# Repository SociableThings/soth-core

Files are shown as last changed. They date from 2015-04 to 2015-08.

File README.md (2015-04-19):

# soth-core

---

## About
Hardware core module for Sociable Things Agent.

## Architecture

Agent



Core

Architecture

## Data format
### GPS
```
{
    "year": 2015,
    "month": 4,
    "day": 12,
    "hour": 14,
    "minute": 0,
    "second": 48,
    "validity": 1,
    "latitude": 35.69020,
    "longitude": 139.69001,
    "speed": 0.74,
    "heading": 102.72
}
```

## Progress

Now prototyping





## GPS bore data

valid GPRMC

```
$GPGGA,150754.000,3540.6036,N,13940.9576,E,2,5,1.85,67.2,M,39.4,M,0000,0000*6A
$GPGLL,3540.6036,N,13940.9576,E,150754.000,A,D*5D
$GPGSA,A,3,28,03,01,06,17,,,,,,,,2.08,1.85,0.95*00
$GPGSV,4,1,13,03,71,081,15,28,56,235,35,17,49,320,16,01,42,051,15*77
$GPGSV,4,2,13,11,32,077,,32,27,046,,06,20,269,35,04,17,067,*76
$GPGSV,4,3,13,23,17,136,,09,05,164,,10,05,213,,44,04,260,*74
$GPGSV,4,4,13,19,03,118,*48
$GPRMC,150754.000,A,3540.6036,N,13940.9576,E,0.06,198.48,110415,,,D*60
$GPVTG,198.48,T,,M,0.06,N,0.12,K,D*31
```

invalid GPRMC

```
$GPRMC,142307.497,V,,,,,0.00,0.00,110415,,,N*44
```

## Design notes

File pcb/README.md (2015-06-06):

# soth-core PCB

---

## BOM list

| Parts # | Parts Name | Manufacture Parts # | Footprint | Pin | Manufacture | Source | Document |
|---:|---:|---:|---:|----:|---:|---:|---:|
| U1| MCU| ATXMEGA32D4-AUR| TQFP| 44| Atmel |[Akizuki](http://akizukidenshi.com/catalog/g/gI-06993/)|[AVR XMEGA D Manual](http://www.atmel.com/ja/jp/Images/Atmel-8210-8-and-16-bit-AVR-Microcontrollers-XMEGA-D_Manual.pdf), [ATxmega32D4 Complete](http://www.atmel.com/ja/jp/Images/Atmel-8135-8-and-16-bit-AVR-microcontroller-ATxmega16D4-32D4-64D4-128D4_datasheet.pdf)|
| IC1|USB Serial Conv.| AE-FT231X(FT231X)|DIP(500MIL)| 18| Akizuki|[Akizuki](http://akizukidenshi.com/catalog/g/gK-06894/)|[Manual](http://akizukidenshi.com/download/ds/akizuki/ae_ft231x_manual.pdf)|
| IC3,4|  3-State Buffer| TC7SZ125F| SSOP| 5| Toshiba|[Akizuki](http://akizukidenshi.com/catalog/g/gI-06481/)|[Datasheet](http://toshiba.semicon-storage.com/info/docget.jsp?did=20048&prodName=TC7SZ125FU)|
| IC5| Pressure Sensor| 12113(LPS331AP)| DIP| 10|Strawberry Linux|[Strawberry Linux](https://strawberry-linux.com/catalog/items?code=12113)|[Manual](https://strawberry-linux.com/pub/lps331ap-manual.pdf)|

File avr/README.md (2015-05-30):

# soth-core-avr

---

## Specification

### MCU
- Type name: ATXMEGA32D4-AU
- Foot print: TQFP44
- Spec
  - 32kB Flash
  - 2kB EEPROM
  - 4kB SRAM
- Voltage: 3.3V
- Xtal: 1MHz

### GPS
- Type name: LS20031(LS23060)
- Voltage: 3.3V
- Update rate: 1 sample/s (default: 5 sample/s)
- Baud rate: 9600bps (default: 57600bps)
- Software UART
  - Rx: PC6
  - Tx: PC7

### Communication
- Baud rate: 115200bps
- Hardware UART
  - USARTC

### Command servo
- Type name: RS304MD
- Motor voltage: 5.0V
- Signal voltage: 3.3V
- Baud rate: 115200bps
- Hardware UART
  - USARTD
- Servo ID
  - 1: Front right
  - 2: Front left
  - 3: Back right
  - 4: Back left
  - 5: Yaw
- Reverse the direction?
  - 1: Yes
  - 2: No
  - 3: No
  - 4: Yes
  - 5: No
- Angle limit: CCW:-16.0 deg, CW: 110.0 deg

## Functions
### CMD Servo
#### Change Servo ID
Change servo ID from 1 to 5

```
changeIdCmdServo(1, 5);
```

#### Revserse direction
```
reverseDirection(1, CMD_SERVO_REVERSE); // reverse
```

#### Change angle limit
```
setAngleLimit(1, CMD_SERVO_ANGLE_LIMIT_MAX, CMD_SERVO_ANGLE_LIMIT_MIN);
```

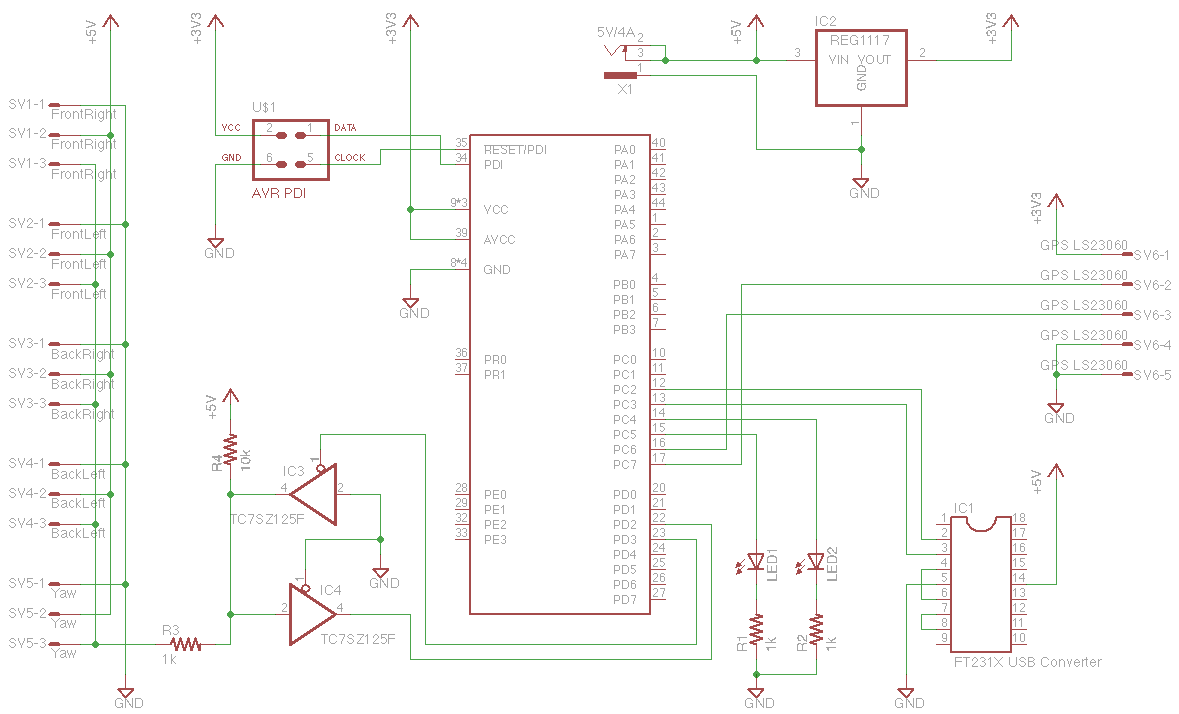
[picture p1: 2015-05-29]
pcb/prototype/schematic.png

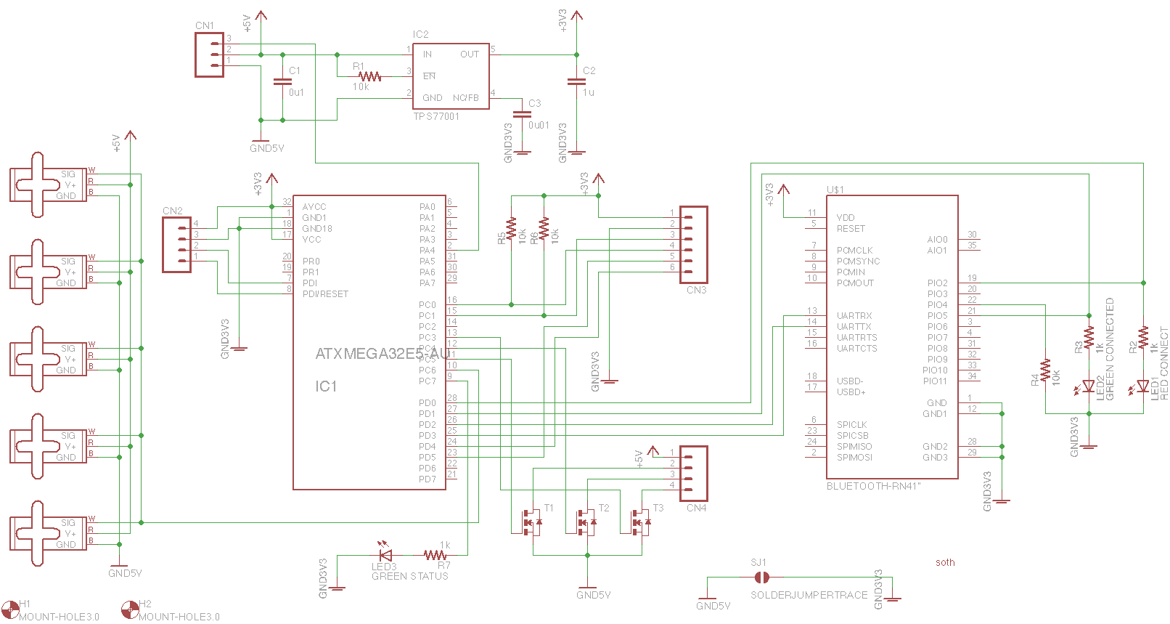
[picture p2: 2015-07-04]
pcb/v0.1/core/soth-core.png

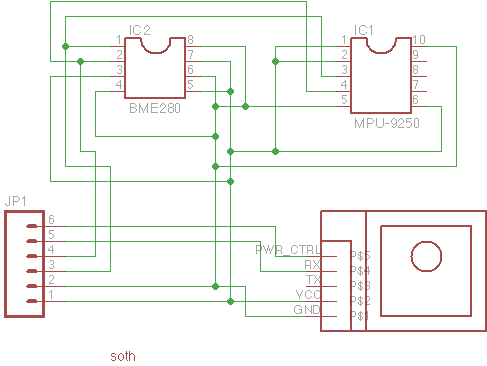
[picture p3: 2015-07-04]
pcb/v0.1/extension/soth-ext.png

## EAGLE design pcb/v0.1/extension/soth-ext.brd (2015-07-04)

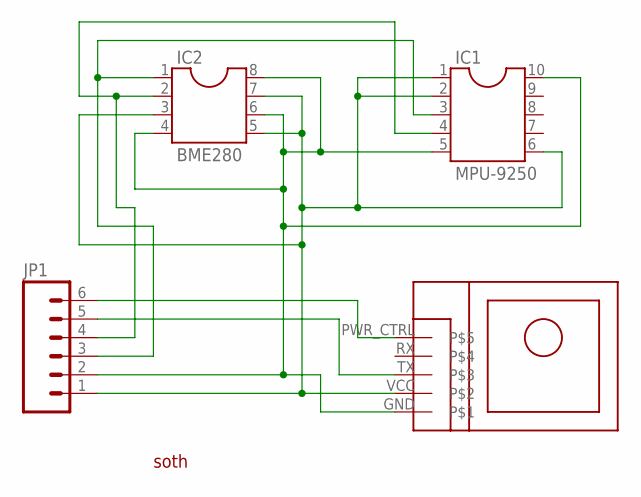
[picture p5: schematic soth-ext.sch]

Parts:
IC1: MPU-9250; DIL10
IC2: BME280; DIL08
JP1: M06SILK_FEMALE_PTH; 1X06
U$1: GM318B
U$2: SOTH_LOGO; SILK_LOGO

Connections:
GND: IC1.5, IC1.10, IC2.4, IC2.6, IC2.8, JP1.2, U$1.GND
unnamed: IC1.1, IC1.2, IC1.6, IC2.3, IC2.5, IC2.7, JP1.1, U$1.VCC
unnamed: JP1.5, U$1.TX
unnamed: JP1.6, U$1.PWR_CTRL
unnamed: IC1.4, IC2.2, JP1.4
unnamed: IC1.3, IC2.1, JP1.3

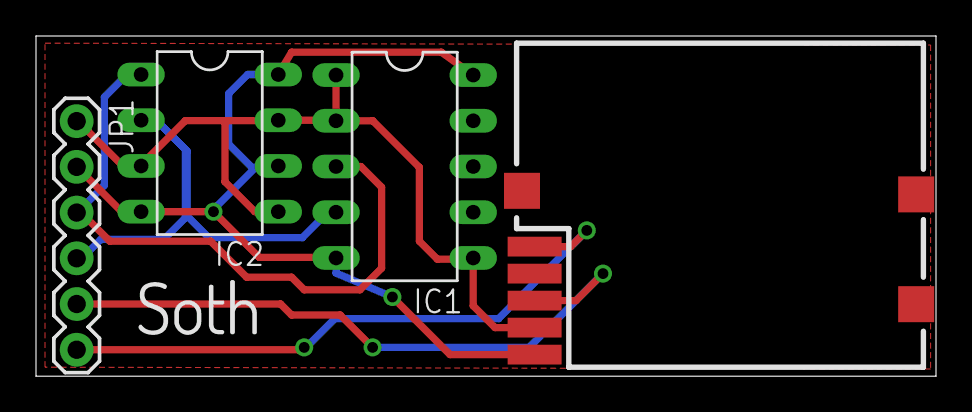
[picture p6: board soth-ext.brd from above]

Board: 2 copper layers, 50.0 x 18.9 mm, 5 parts (0 on the bottom side), 6 nets.

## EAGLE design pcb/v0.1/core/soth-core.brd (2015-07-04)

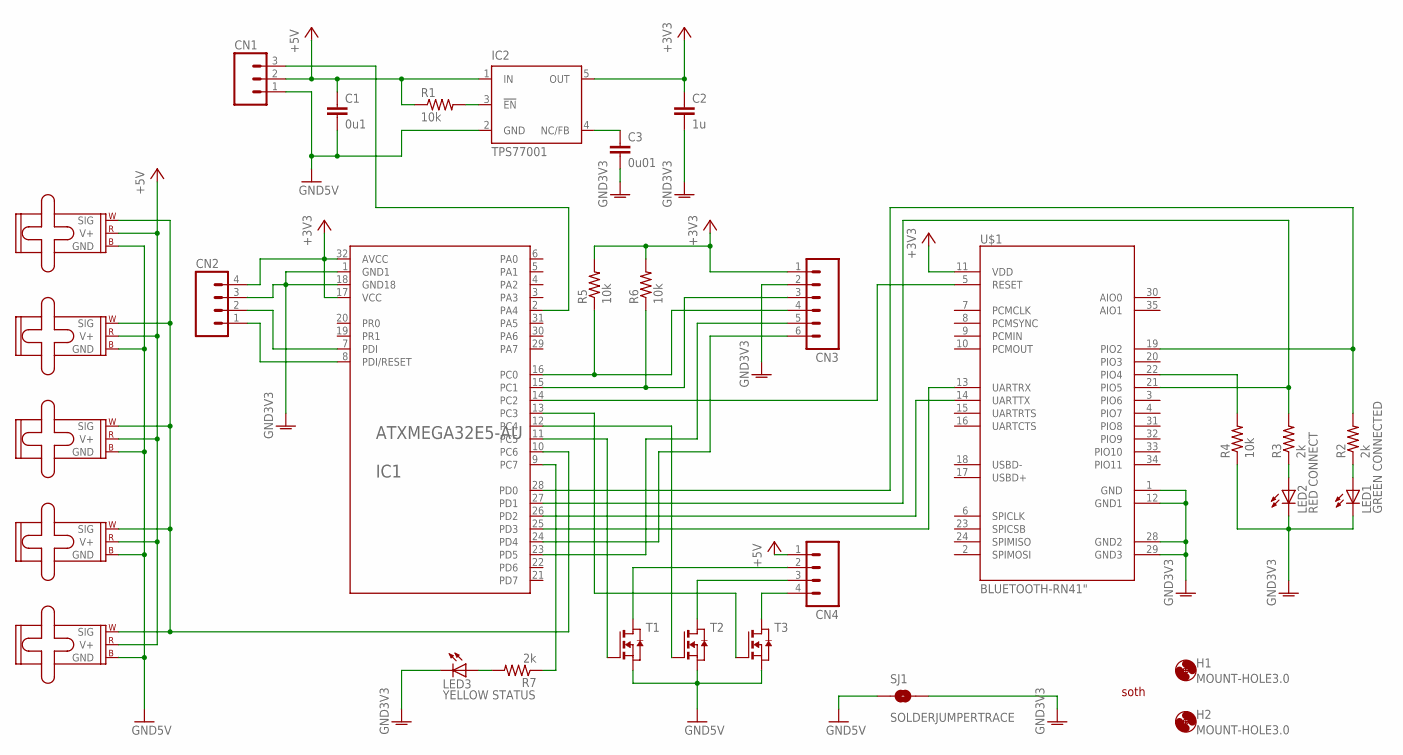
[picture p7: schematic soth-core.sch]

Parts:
C1: 0u1; C1608
C2: 1u; C1608
C3: 0u01; C1608
CN1: M03PTH; 1X03
CN2, CN4: M04PTH; 1X04
CN3: M06SILK_FEMALE_PTH; 1X06
H1, H2: MOUNT-HOLE3.0; 3,0
IC1: ATXMEGA32E5-AU; TQFP32-08
IC2: TPS77001; SOT23-DBV
LED1: GREEN CONNECTED; CHIPLED_1206
LED2: RED CONNECT; CHIPLED_1206
LED3: YELLOW STATUS; CHIPLED_1206
M1, M2, M3, M4, M5: SMALL_SERVO; 1X03
R1, R4, R5, R6: 10k; R0603
R2, R3, R7: 2k; R0603
SJ1: SOLDERJUMPERTRACE; SJ_2S-TRACE
T1, T2, T3: NMOSSOT23; SOT-23
U$1: BLUETOOTH-RN41"; RN41
U$2: SOTH_LOGO; SILK_LOGO

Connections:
+3V3: C2.1, CN2.4, CN3.1, IC1.17 (VCC), IC1.32 (AVCC), IC2.5 (OUT), R5.2, R6.2, U$1.11 (VDD)
+5V: C1.1, CN1.2, CN4.1, IC2.1 (IN), M1.2 (V+), M2.2 (V+), M3.2 (V+), M4.2 (V+), M5.2 (V+), R1.1
GND: C1.2, CN1.1, IC2.2 (GND), M1.3 (GND), M2.3 (GND), M3.3 (GND), M4.3 (GND), M5.3 (GND), SJ1.1, T1.2 (S), T2.2 (S), T3.2 (S)
GNDA: C2.2, C3.2, CN2.3, CN3.2, IC1.1 (GND1), IC1.18 (GND18), LED1.C, LED2.C, LED3.C, R4.1, SJ1.2, U$1.1 (GND), U$1.12 (GND1), U$1.28 (GND2), U$1.29 (GND3)
unnamed: CN4.2, T1.1 (D)
unnamed: IC2.3 (!EN), R1.2
unnamed: IC1.26 (PD2), U$1.14 (UARTTX)
unnamed: CN2.2, IC1.7 (PDI)
unnamed: CN2.1, IC1.8 (PDI/RESET)
unnamed: IC1.25 (PD3), U$1.13 (UARTRX)
unnamed: IC1.27 (PD1), R3.2, U$1.21 (PIO5)
unnamed: LED2.A, R3.1
unnamed: LED1.A, R2.1
unnamed: IC1.28 (PD0), R2.2, U$1.19 (PIO2)
unnamed: R4.2, U$1.22 (PIO4)
unnamed: CN3.4, IC1.16 (PC0), R5.1
unnamed: CN3.3, IC1.15 (PC1), R6.1
unnamed: CN1.3, IC1.2 (PA4)
unnamed: CN4.3, T2.1 (D)
unnamed: CN4.4, T3.1 (D)
unnamed: IC1.9 (PC7), R7.1
unnamed: IC1.11 (PC5), T1.3 (G)
unnamed: CN3.6, IC1.24 (PD4)
unnamed: IC1.10 (PC6), M1.1 (SIG), M2.1 (SIG), M3.1 (SIG), M4.1 (SIG), M5.1 (SIG)
unnamed: CN3.5, IC1.23 (PD5)
unnamed: IC1.12 (PC4), T2.3 (G)
unnamed: IC1.13 (PC3), T3.3 (G)
unnamed: LED3.A, R7.2
unnamed: C3.1, IC2.4 (NC/FB)
unnamed: IC1.14 (PC2), U$1.5 (RESET)

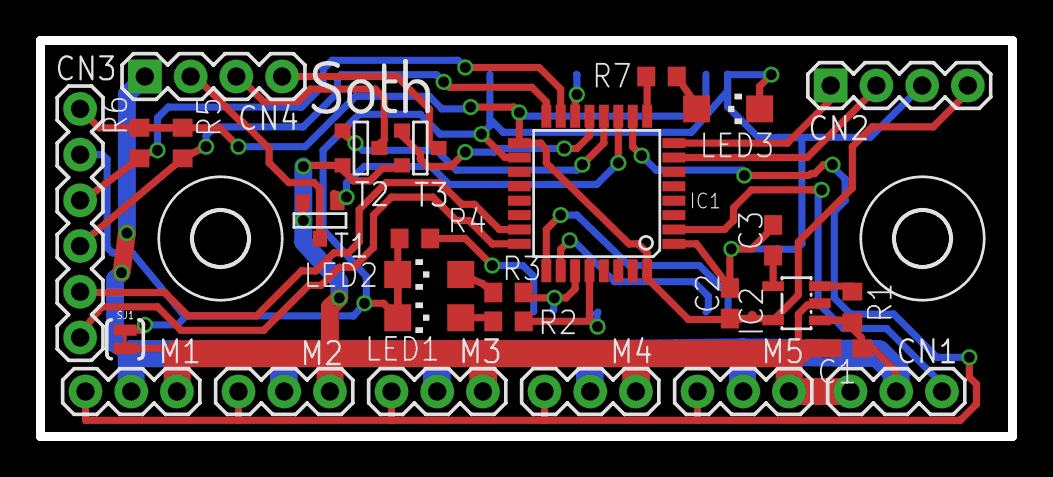
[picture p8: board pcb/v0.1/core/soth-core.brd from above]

Board: 2 copper layers, 54.0 x 22.0 mm, 32 parts (1 on the bottom side), 30 nets.

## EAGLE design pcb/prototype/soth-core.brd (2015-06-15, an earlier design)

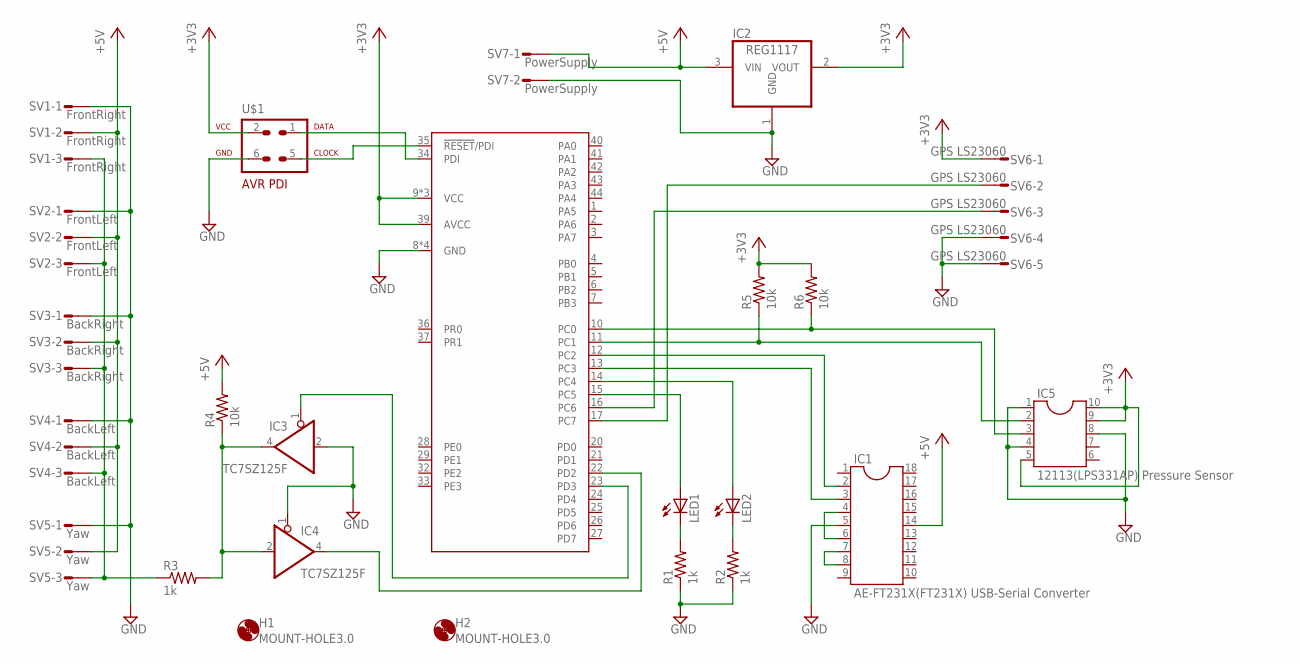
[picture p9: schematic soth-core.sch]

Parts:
H1, H2: MOUNT-HOLE3.0; 3,0
IC1: AE-FT231X(FT231X) USB-Serial Converter; SOCKET-18
IC2: REG1117; SOT223
IC3, IC4: TC7SZ125F; SOT23-5
IC5: 12113(LPS331AP) Pressure Sensor; DIL10
LED1, LED2: LED; SMARTLED-TTW
R1, R2, R3: 1k; R0805
R4, R5, R6: 10k; R0805
SV1: FrontRight; S03P
SV2: FrontLeft; S03P
SV3: BackRight; S03P
SV4: BackLeft; S03P
SV5: Yaw; S03P
SV6: GPS LS23060; S05P
SV7: PowerSupply; S02P
U1: ATXMEGA32D4-AU; TQFP-44A-44
U$1: AVR-PDIVERT; AVR-ISP-6

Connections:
+3V3: IC2.2 (VOUT), IC5.5, IC5.9, IC5.10, R5.2, R6.2, SV6.1, U1.9 (VCC), U1.19 (VCC), U1.31 (VCC), U1.39 (AVCC), U$1.2
+5V: IC1.14, IC2.3 (VIN), R4.2, SV1.2, SV2.2, SV3.2, SV4.2, SV5.2, SV7.1
GND: IC1.5, IC2.1 (GND), IC3.2 (I), IC3.3 (GND), IC4.1 (OE), IC4.3 (GND), IC5.1, IC5.4, IC5.8, R1.1, R2.1, SV1.1, SV2.1, SV3.1, SV4.1, SV5.1, SV6.4, SV6.5, SV7.2, U1.8 (GND), U1.18 (GND), U1.30 (GND), U1.38 (GND), U$1.6
unnamed: R3.1, SV1.3, SV2.3, SV3.3, SV4.3, SV5.3
unnamed: LED1.A@1 (A), U1.15 (PC5)
unnamed: LED2.A@1 (A), U1.14 (PC4)
unnamed: LED1.C@1 (C), R1.2
unnamed: U1.35 (!RESET!/PDI), U$1.5
unnamed: U1.34 (PDI), U$1.1
unnamed: LED2.C@1 (C), R2.2
unnamed: IC4.4 (O), U1.22 (PD2)
unnamed: SV6.2, U1.17 (PC7)
unnamed: IC1.2, U1.12 (PC2)
unnamed: IC1.3, U1.13 (PC3)
unnamed: IC1.7, IC1.8
unnamed: IC1.4, IC1.6
unnamed: SV6.3, U1.16 (PC6)
unnamed: IC3.1 (OE), U1.23 (PD3)
unnamed: IC3.4 (O), IC4.2 (I), R3.2, R4.1
unnamed: IC5.3, R6.1, U1.10 (PC0)
unnamed: IC5.2, R5.1, U1.11 (PC1)
VCC: IC3.5 (VCC), IC4.5 (VCC)

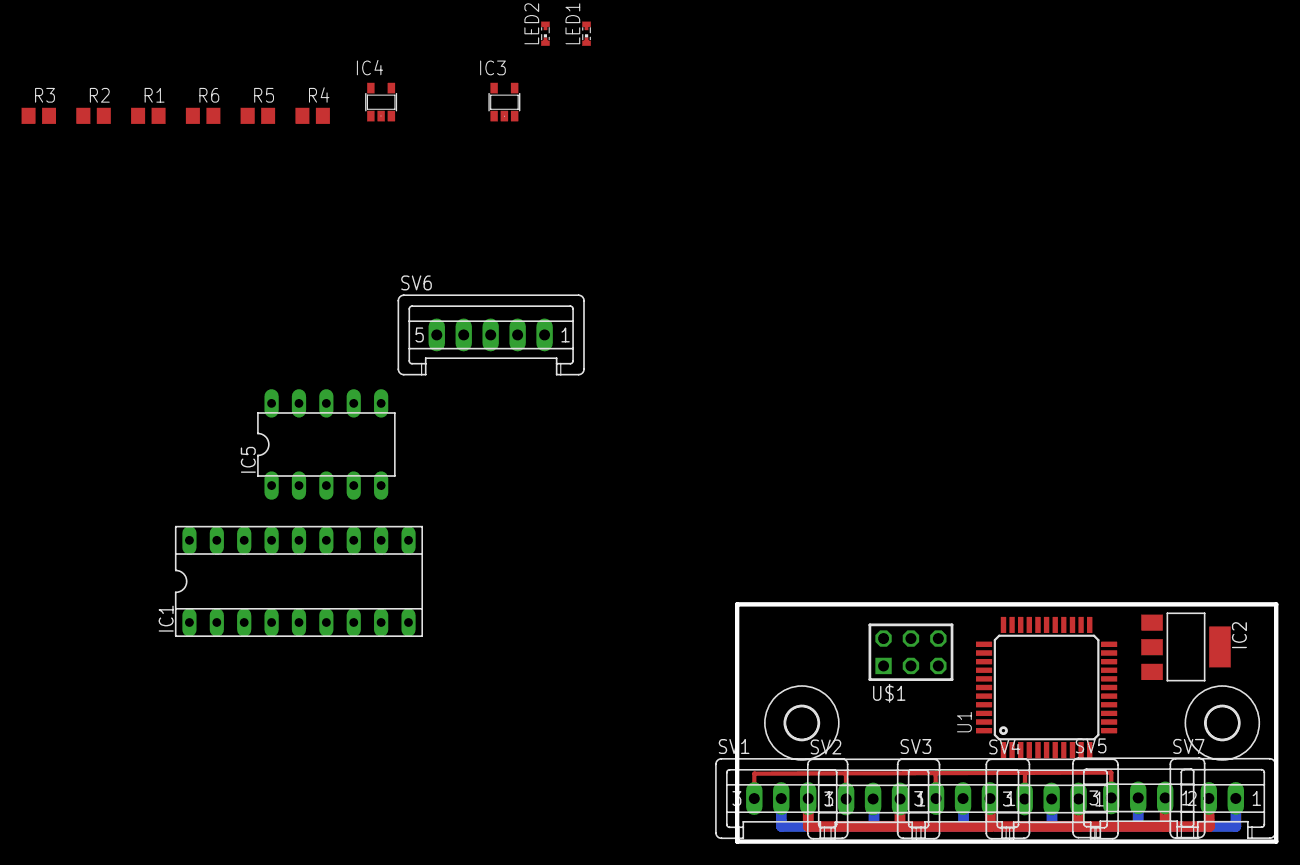
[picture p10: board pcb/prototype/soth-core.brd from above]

Board: 2 copper layers, 50.0 x 22.0 mm, 24 parts (0 on the bottom side), 22 nets.

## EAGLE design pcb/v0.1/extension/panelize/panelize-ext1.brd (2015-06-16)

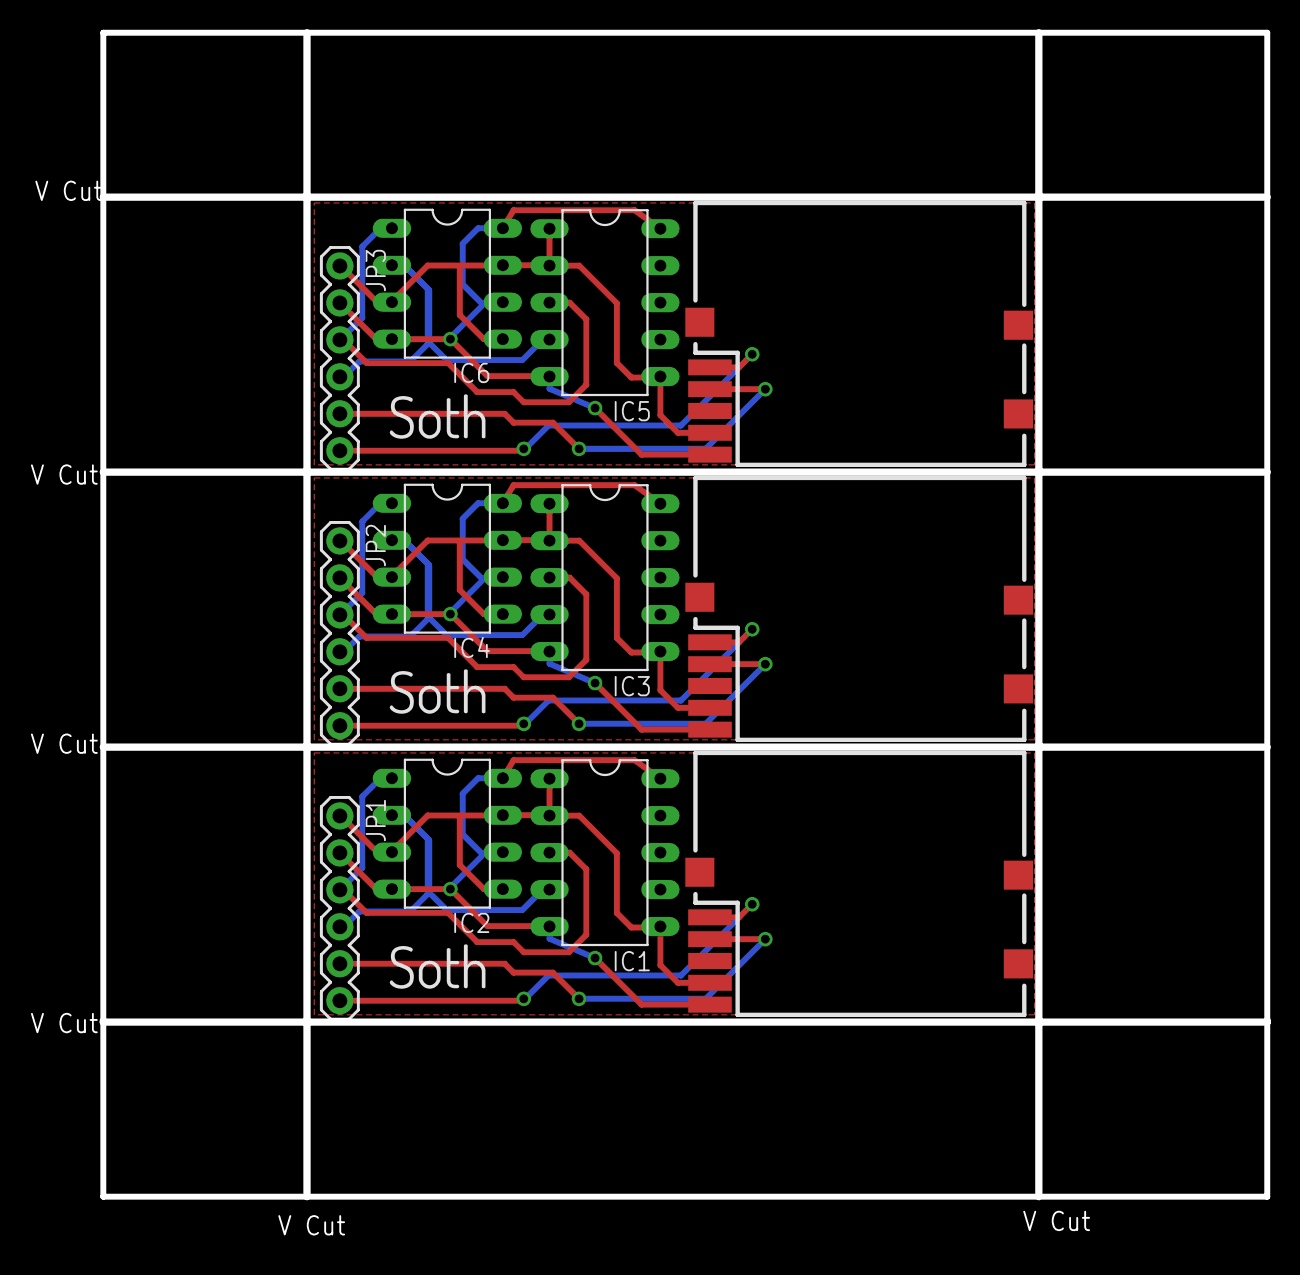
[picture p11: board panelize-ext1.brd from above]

Board: 2 copper layers, 80.0 x 80.0 mm, 15 parts (0 on the bottom side), 18 nets.

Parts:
IC1, IC3, IC5: MPU-9250; DIL10
IC2, IC4, IC6: BME280; DIL08
JP1, JP2, JP3: 1X06
U$1, U$3, U$5: GM318B
U$2, U$4, U$6: SOTH_LOGO; SILK_LOGO

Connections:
GND: IC1.5, IC1.10, IC2.4, IC2.6, IC2.8, JP1.2, U$1.GND
GND1: IC3.5, IC3.10, IC4.4, IC4.6, IC4.8, JP2.2, U$3.GND
GND2: IC5.5, IC5.10, IC6.4, IC6.6, IC6.8, JP3.2, U$5.GND
unnamed: JP2.5, U$3.RX
unnamed: IC1.1, IC1.2, IC1.6, IC2.3, IC2.5, IC2.7, JP1.1, U$1.VCC
unnamed: JP1.5, U$1.RX
unnamed: JP1.6, U$1.PWR_CTRL
unnamed: JP2.6, U$3.PWR_CTRL
unnamed: IC3.4, IC4.2, JP2.4
unnamed: IC1.4, IC2.2, JP1.4
unnamed: IC1.3, IC2.1, JP1.3
unnamed: IC3.3, IC4.1, JP2.3
unnamed: IC3.1, IC3.2, IC3.6, IC4.3, IC4.5, IC4.7, JP2.1, U$3.VCC
unnamed: JP3.5, U$5.RX
unnamed: JP3.6, U$5.PWR_CTRL
unnamed: IC5.4, IC6.2, JP3.4
unnamed: IC5.3, IC6.1, JP3.3
unnamed: IC5.1, IC5.2, IC5.6, IC6.3, IC6.5, IC6.7, JP3.1, U$5.VCC

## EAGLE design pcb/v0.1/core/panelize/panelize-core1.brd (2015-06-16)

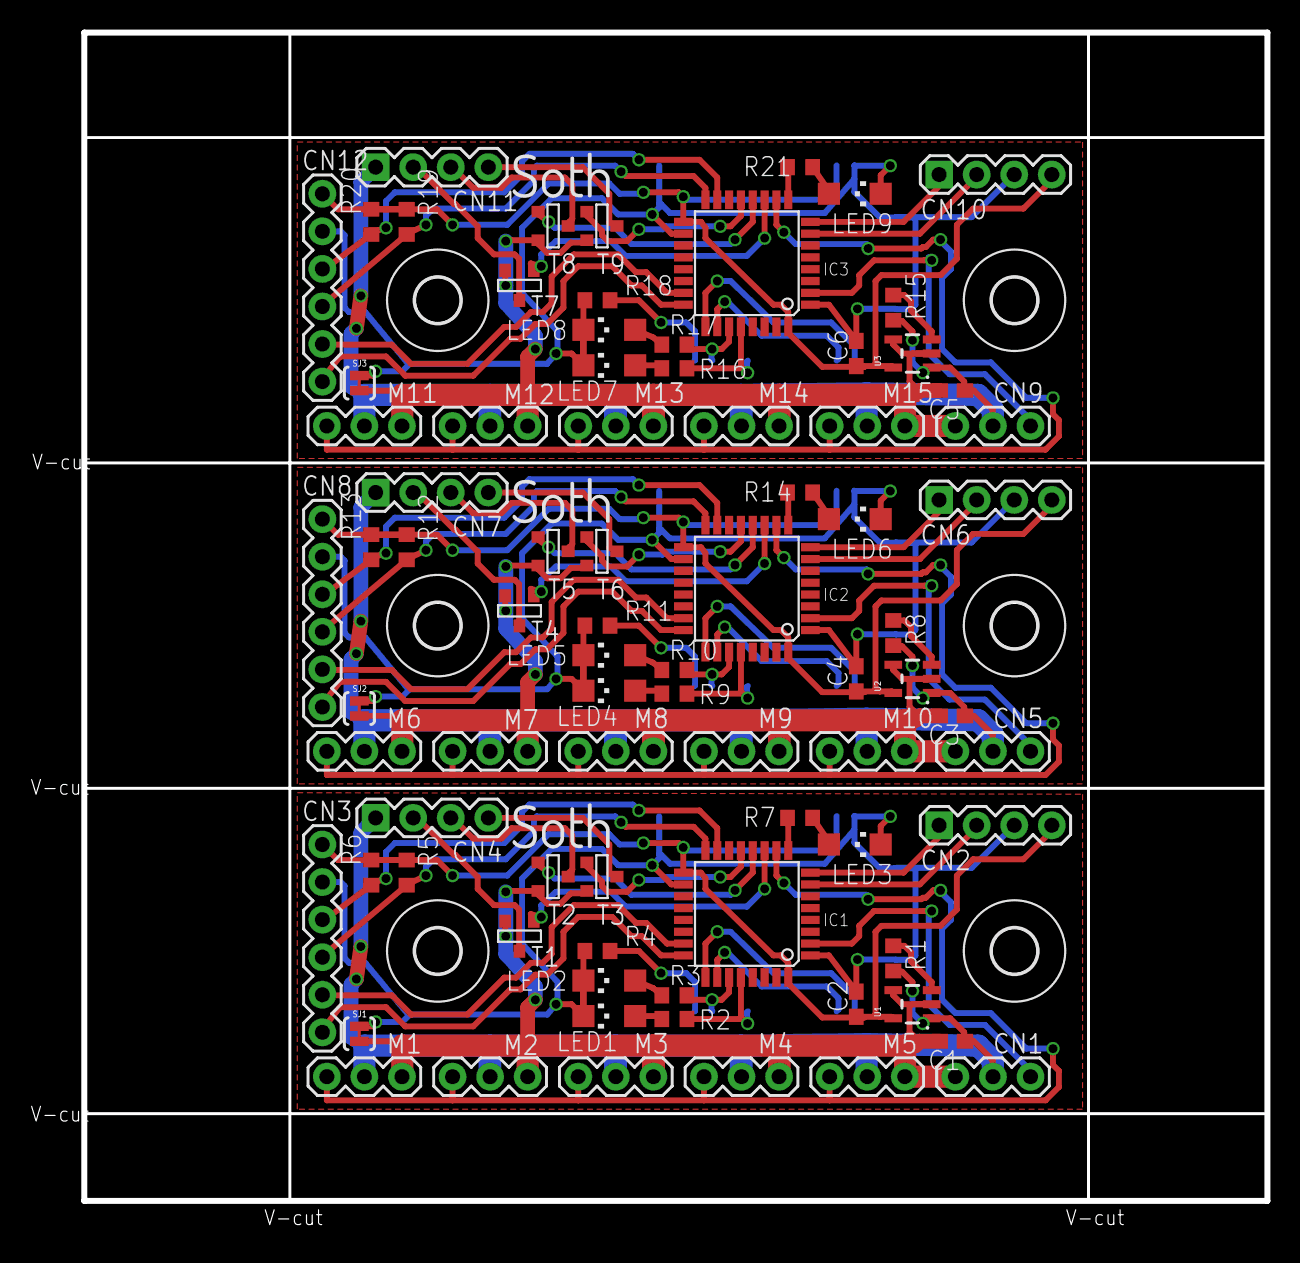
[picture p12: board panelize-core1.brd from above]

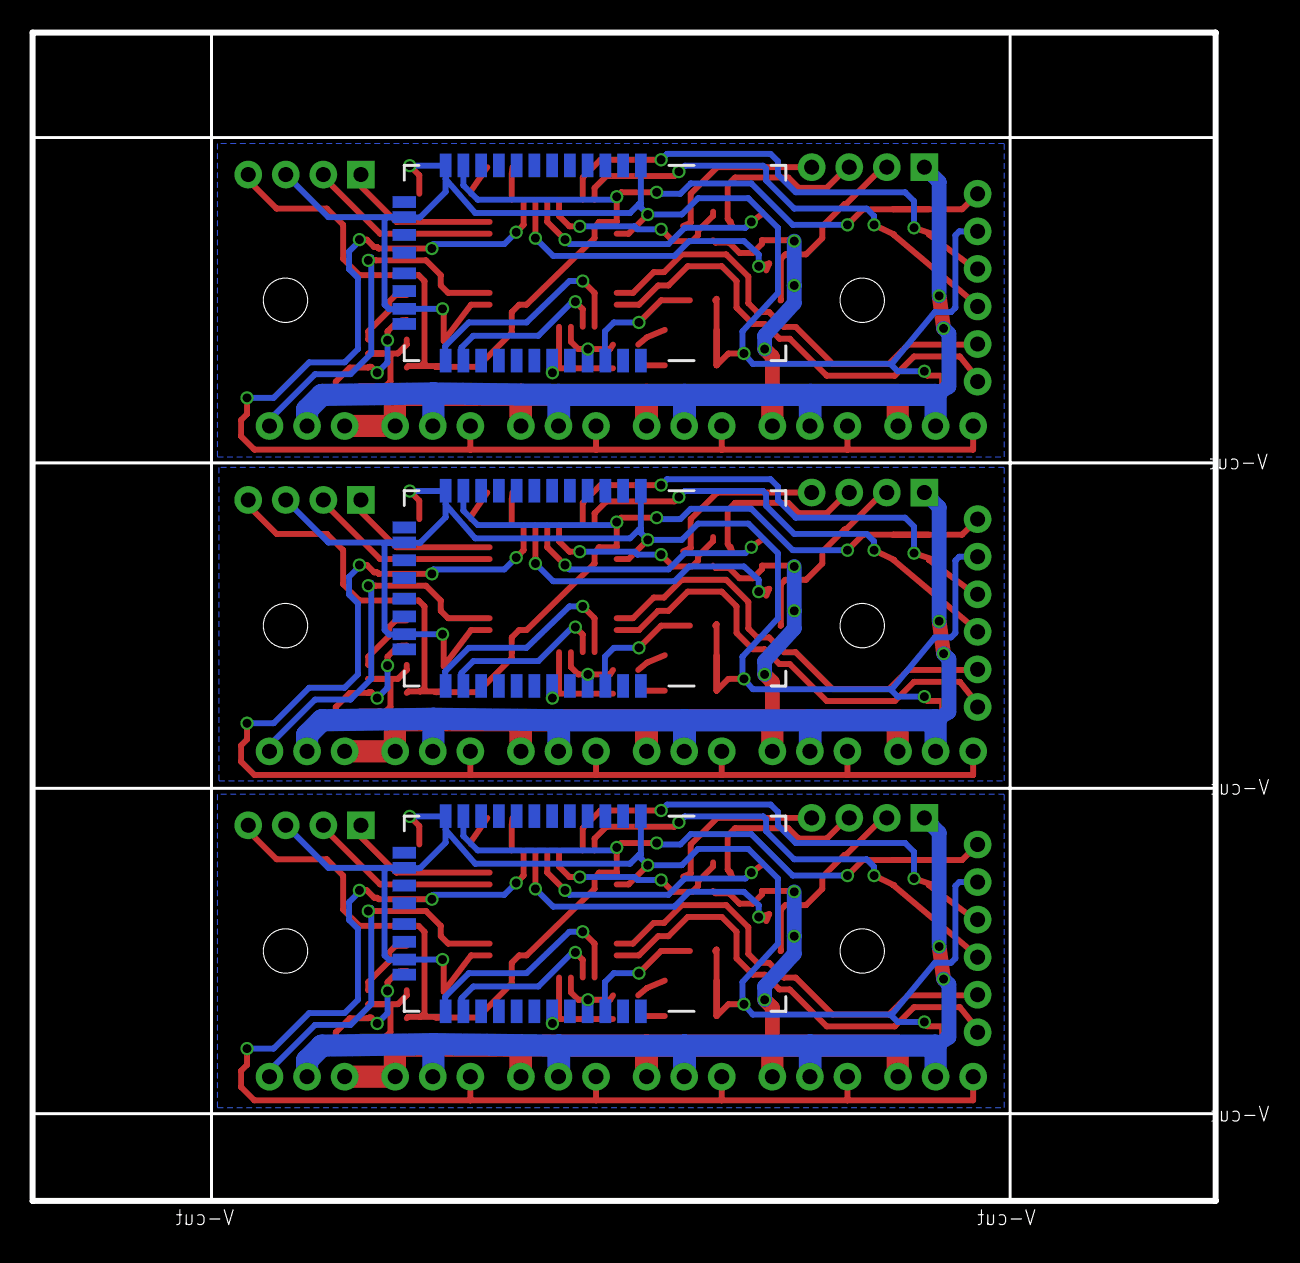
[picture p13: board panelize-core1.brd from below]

Board: 2 copper layers, 80.0 x 79.0 mm, 93 parts (3 on the bottom side), 84 nets.

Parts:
C1, C3, C5: 0u1; C1608
C2, C4, C6: 1u; C1608
CN1, CN5, CN9: 1X03
CN2, CN4, CN6, CN7, CN10, CN11: 1X04
CN3, CN8, CN12: 1X06
H1, H2, H3, H4, H5, H6: MOUNT-HOLE3.0; 3,0
IC1, IC2, IC3: ATXMEGA32E5-AU; TQFP32-08
LED1, LED4, LED7: RED CONNECT; CHIPLED_1206
LED2, LED5, LED8: GREEN CONNECTED; CHIPLED_1206
LED3, LED6, LED9: GREEN STATUS; CHIPLED_1206
M1, M2, M3, M4, M5, M6, M7, M8, M9, M10, M11, M12, M13, M14, M15: SMALL_SERVO; 1X03
R1, R4, R5, R6, R8, R11, R12, R13, R15, R18, R19, R20: 10k; R0603
R2, R3, R7, R9, R10, R14, R16, R17, R21: 1k; R0603
SJ1, SJ2, SJ3: SOLDERJUMPERTRACE; SJ_2S-TRACE
T1, T2, T3, T4, T5, T6, T7, T8, T9: SOT-23
U1, U2, U3: LDO-TPS78233; SOT23-5
U$1, U$3, U$5: BLUETOOTH-RN41"; RN41
U$2, U$4, U$6: SOTH_LOGO; SILK_LOGO

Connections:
+3V1: C4.1, CN6.4, CN8.1, IC2.17, IC2.32, R12.2, R13.2, U2.5, U$3.11
+3V2: C6.1, CN10.4, CN12.1, IC3.17, IC3.32, R19.2, R20.2, U3.5, U$5.11
+3V3: C2.1, CN2.4, CN3.1, IC1.17, IC1.32, R5.2, R6.2, U1.5, U$1.11
+5V: C1.1, CN1.2, CN4.1, M1.2, M2.2, M3.2, M4.2, M5.2, R1.1, U1.1
+5V1: C3.1, CN5.2, CN7.1, M6.2, M7.2, M8.2, M9.2, M10.2, R8.1, U2.1
+5V2: C5.1, CN9.2, CN11.1, M11.2, M12.2, M13.2, M14.2, M15.2, R15.1, U3.1
GND: C1.2, CN1.1, M1.3, M2.3, M3.3, M4.3, M5.3, SJ1.1, T1.2, T2.2, T3.2, U1.2, U1.4
GND1: C3.2, CN5.1, M6.3, M7.3, M8.3, M9.3, M10.3, SJ2.1, T4.2, T5.2, T6.2, U2.2, U2.4
GND2: C5.2, CN9.1, M11.3, M12.3, M13.3, M14.3, M15.3, SJ3.1, T7.2, T8.2, T9.2, U3.2, U3.4
GNDA: C2.2, CN2.3, CN3.2, IC1.1, IC1.18, LED1.C, LED2.C, LED3.C, R4.1, SJ1.2, U$1.1, U$1.12, U$1.28, U$1.29
GNDA1: C4.2, CN6.3, CN8.2, IC2.1, IC2.18, LED4.C, LED5.C, LED6.C, R11.1, SJ2.2, U$3.1, U$3.12, U$3.28, U$3.29
GNDA2: C6.2, CN10.3, CN12.2, IC3.1, IC3.18, LED7.C, LED8.C, LED9.C, R18.1, SJ3.2, U$5.1, U$5.12, U$5.28, U$5.29
unnamed: CN4.2, T1.1
unnamed: R1.2, U1.3
unnamed: IC1.26, U$1.14
unnamed: CN2.2, IC1.7
unnamed: CN2.1, IC1.8
unnamed: IC1.25, U$1.13
unnamed: IC1.27, R3.2, U$1.21
unnamed: LED2.A, R3.1
unnamed: LED1.A, R2.1
unnamed: IC1.28, R2.2, U$1.19
unnamed: R4.2, U$1.22
unnamed: CN3.4, IC1.16, R5.1
unnamed: CN3.3, IC1.15, R6.1
unnamed: CN1.3, IC1.2
unnamed: CN4.3, T2.1
unnamed: CN4.4, T3.1
unnamed: IC1.9, R7.1
unnamed: IC1.11, T1.3
unnamed: CN3.6, IC1.24
unnamed: IC1.10, M1.1, M2.1, M3.1, M4.1, M5.1
unnamed: CN3.5, IC1.23
unnamed: IC1.12, T2.3
unnamed: IC1.13, T3.3
unnamed: LED3.A, R7.2
unnamed: R8.2, U2.3
unnamed: CN6.2, IC2.7
unnamed: CN6.1, IC2.8
unnamed: IC2.26, U$3.14
unnamed: IC2.25, U$3.13
unnamed: IC2.27, R10.2, U$3.21
unnamed: LED5.A, R10.1
unnamed: LED4.A, R9.1
unnamed: IC2.28, R9.2, U$3.19
unnamed: R11.2, U$3.22
unnamed: CN8.4, IC2.16, R12.1
unnamed: CN8.3, IC2.15, R13.1
unnamed: CN5.3, IC2.2
unnamed: IC2.10, M6.1, M7.1, M8.1, M9.1, M10.1
unnamed: CN8.6, IC2.24
unnamed: CN8.5, IC2.23
unnamed: CN7.2, T4.1
unnamed: CN7.3, T5.1
unnamed: CN7.4, T6.1
unnamed: IC2.11, T4.3
unnamed: IC2.12, T5.3
unnamed: IC2.13, T6.3
unnamed: IC2.9, R14.1
unnamed: LED6.A, R14.2
unnamed: R15.2, U3.3
unnamed: CN10.2, IC3.7
unnamed: CN10.1, IC3.8
unnamed: IC3.26, U$5.14
unnamed: IC3.25, U$5.13
unnamed: IC3.27, R17.2, U$5.21
unnamed: LED8.A, R17.1
unnamed: LED7.A, R16.1
unnamed: IC3.28, R16.2, U$5.19
unnamed: R18.2, U$5.22
unnamed: CN12.4, IC3.16, R19.1
unnamed: CN12.3, IC3.15, R20.1
unnamed: CN9.3, IC3.2
unnamed: IC3.10, M11.1, M12.1, M13.1, M14.1, M15.1
unnamed: CN12.6, IC3.24
unnamed: CN12.5, IC3.23
unnamed: CN11.2, T7.1
unnamed: CN11.3, T8.1
unnamed: CN11.4, T9.1
unnamed: IC3.11, T7.3
unnamed: IC3.12, T8.3
unnamed: IC3.13, T9.3
unnamed: IC3.9, R21.1
unnamed: LED9.A, R21.2

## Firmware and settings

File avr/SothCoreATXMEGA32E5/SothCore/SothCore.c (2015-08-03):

/*
 * SothCore.c
 *
 * Author: Hideyuki Takei <hide@soth.io>
 */

#include <avr/io.h>
#include <util/delay.h>
#include <avr/pgmspace.h>
#include <avr/interrupt.h>  
#include <stdlib.h>
#include "SothCore.h"
#include "UsartCommunication.h"
#include "UsartGPS.h"
#include "I2C.h"
#include "BME280.h"
#include "UsartCmdServo.h"
#include "xprintf.h"
#include "MotionControl.h"
#include "MPU9150.h"

#define WAIT_TIME 200
#define UP_ANGLE 900
#define DOWN_ANGLE 700
#define CLOSE_ANGLE 0
#define RIGHT_YAW 200
#define LEFT_YAW -200
#define CENTER_YAW -30

// Prototypes
void initClock();
void initPort();
void onReadSensor(float temperature, float pressure, float humidity);
void onReadAccSensor(int16_t accX, double accY, double accZ);

int main(void)
{	
	char jsonString[1000];
    uint8_t servoData[200];

    // Initialization
	initPort();
	initClock();
	initUsartComm();
	initUsartGPS();
    initI2C();
	initUsartCmdServo();
    initBME280();
    initMPU9150();

    // Enable interrupt
    PMIC_CTRL =  PMIC_LOLVLEN_bm | PMIC_MEDLVLEN_bm | PMIC_HILVLEN_bm;  // enable high/middle level interrupt executing
    sei();

    _delay_ms(1000);

    /*while(1){
        readAccGyro(onReadAccSensor);
        _delay_ms(2000);
    }*/

    //setStandaloneMotion();
    setOldStandaloneMotion();

    // LED test
    /*
    while(1){
        offLedStatus();
        _delay_ms(1000);
        onLedStatus();
        _delay_ms(1000);
        xprintf("hogege\r\n");
        //_delay_ms(1000);
        //xprintf("R,1\r\n");
    }
    */
    
    /*// GPS test
    powerOnGPS();
    while(1)
    {
		onLedStatus();
		_delay_ms(100);
		offLedStatus();
		_delay_ms(100);
        
        getGPRMCInfoAsJson(jsonString);
        //sendStringToComm(jsonString);

        _delay_ms(1000);
    }*/
    
    /*// I2C test
    uint8_t data[] = {0x20, 0x90};
    addQueue(0b10111000, 2, data, 0, testI2C);

    _delay_ms(2000);
    
    uint8_t data2[] = {0x28};
    addQueue(0b10111000, 1, data2, 1, testI2C);

    uint8_t data3[] = {0x29};
    addQueue(0b10111000, 1, data3, 1, testI2C);

    uint8_t data4[] = {0x2A};
    addQueue(0b10111000, 1, data4, 1, testI2C);*/

    
    /*// Temperature, pressure, humidity
    _delay_ms(1000);

    initBME280();

    while(1){
        //uint8_t address[] = {0xD0};
        //addQueue(0b11101100, 1, address, 1, testI2C);
        //address[0] = 0x75;
        //addQueue(0b11010000, 1, address, 1, testI2C);
        readTemperaturePressureHumidity(onReadSensor);

        _delay_ms(5000);

        onLedStatus();
        _delay_ms(100);
        offLedStatus();
        _delay_ms(100);
    }*/
    

    /*// Proto3 test
    uint8_t buffer[128];
    size_t message_length;
    bool status;

    RobotInfoRequest request;
    pb_ostream_t stream = pb_ostream_from_buffer(buffer, sizeof(buffer));
    request.robot_id = 10;

    status = pb_encode(&stream, RobotInfoRequest_fields, &request);
    message_length = stream.bytes_written;

    if (!status)
    {
        xprintf("Encoding failed: %s\n", PB_GET_ERROR(&stream));
        return 1;
    }

    RobotInfoRequest req2;
    pb_istream_t stream2 = pb_istream_from_buffer(buffer, message_length);
    status = pb_decode(&stream2, RobotInfoRequest_fields, &req2);

    if (!status)
    {
        xprintf("Decoding failed: %s\n", PB_GET_ERROR(&stream2));
        return 1;
    }

    onLedStatus();
    while(1){
        uint16_t length = recvCharacters(servoData, 3);
        if(length>0){
            break;
        }
    }
    _delay_ms(1000);

    while(1){
        onLedStatus();
        _delay_ms(500);
        offLedStatus();
        _delay_ms(500);
        xprintf("Your lucky number was %d!\n", req2.robot_id);
    }*/

    /*
    // pb test
    _delay_ms(500);
    
    changeTorqueOnForAllServos();

    while(1){
        //onLedStatus();
        _delay_ms(500);
        //offLedStatus();
    }*/
}

void onReadAccSensor(int16_t accX, double accY, double accZ)
{

}

void onReadSensor(float temperature, float pressure, float humidity)
{
    char temperatureString[20], pressureString[20], humidityString[20];
    
    xprintf("## Recv sensor\n");
    
    dtostrf(temperature, 2, 2, temperatureString);
    dtostrf(pressure, 2, 2, pressureString);
    dtostrf(humidity, 2, 2, humidityString);
    xprintf("Temperature: %sdeg, Pressure: %shPa, Humidity: %s%%\n", temperatureString, pressureString, humidityString);
}

void initClock()
{
	// Set int. 2MHz Clock
	OSC.CTRL = OSC_RC2MEN_bm;
	loop_until_bit_is_set(OSC.STATUS, OSC_RC2MRDY_bp);

	// Set clock selector: Int. 2MHz
	CPU_CCP = CCP_IOREG_gc;
	CLK.CTRL = CLK_SCLKSEL_RC2M_gc;
	
	// Set Pre-scaler DIV2 (Sys CLK: 1MHz)
	CPU_CCP = CCP_IOREG_gc;
	CLK.PSCTRL = CLK_PSADIV_2_gc;
}

void initPort()
{    
    // PORTA:     11101111
    //            |||||||+- PA0( 6): NC
    //            ||||||+-- PA1( 5): NC
    //            |||||+--- PA2( 4): NC
    //            ||||+---- PA3( 3): NC
    //            |||+----- PA4( 2): Power voltage ADC
    //            ||+------ PA5(31): NC
    //            |+------- PA6(30): NC
    //            +-------- PA7(29): NC
    PORTA_DIR = 0b11101111;
    PORTA_OUT = 0b11101111;

    // PORTC:     11111110
    //            |||||||+- PC0(16): SDA I2C for sensors
    //            ||||||+-- PC1(15): SCL I2C for sensors
    //            |||||+--- PC2(14): Bluetooth /RESET (Active low)
    //            ||||+---- PC3(13): Eye LED(Red)
    //            |||+----- PC4(12): Eye LED(Green)
    //            ||+------ PC5(11): Eye LED(Blue)
    //            |+------- PC6(10): RXC0 Command Servo (One wire half duplex)
    //            +-------- PC7( 9): Status LED(Yellow)
	PORTC_DIR = 0b11111110;
	PORTC_OUT = 0b11111110;
    PORTC_REMAP = 0b00010000; // Remap USARTC0 from PC0-3 to PC4-7
	
    // PORTD:     11011000
    //            |||||||+- PD0(28): Port of Bluetooth Connected LED(Red)
    //            ||||||+-- PD1(27): Port of Bluetooth Connect LED(Green)
    //            |||||+--- PD2(26): RXD0 Bluetooth SPP
    //            ||||+---- PD3(25): TXD0 Bluetooth SPP
    //            |||+----- PD4(24): Power Control of GPS (Active low)
    //            ||+------ PD5(23): Software UART RX for GPS
    //            |+------- PD6(22): NC
    //            +-------- PD7(21): NC
    PORTD_DIR = 0b11011000;
	PORTD_OUT = 0b11001000;

	offLedStatus();
    powerOffGPS();

    // Virtual Port
    // VPORT0: Virtual Port A
    // VPORT1: Virtual Port C
    // VPORT2: Virtual Port D
    // VPORT3: Virtual Port R
}

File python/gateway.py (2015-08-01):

#!/usr/bin/env python

import soth_pb2
import serial
import time

from scipy import arange, sin
from scipy import pi as mpi
from matplotlib import pylab as pl

ser = serial.Serial('/dev/cu.RNBT-75B9-RNI-SPP', 115200, timeout=10)
time.sleep(1)

MIN_POSITION = 150
MAX_POSITION = 900
CENTER_POSITION = 700

def make_sine(Freq, Amp, fs, sec = 2.):
  ret = Amp * sin(2. * mpi * Freq * arange(int(fs * sec)) / fs)
  return ret

def sendData(fr, fl, br, bl, y):
  for i in range(0, 3):
    servo_position = soth_pb2.ServoPosition()

    servo_position.servo_front_right = fr
    servo_position.servo_front_left = fl
    servo_position.servo_back_right = br
    servo_position.servo_back_left = bl
    servo_position.servo_yaw = y

    ser.write(servo_position.SerializeToString())
    ser.write("\0")

    #msg = servo_position.SerializeToString()
    #sp = servo_position.ParseFromString(msg)

  #ser.close()

F_default = 1
A_default = 200
WAIT_TIME = 50
fs_default = 200

def test():
  sine_wave = make_sine(F_default, A_default, fs_default)

  while True:
    for i in range(0, len(sine_wave)):
      d = int(sine_wave[i]) + CENTER_POSITION
      print d
      #sendData(d, d, d, d, -30)
      ser.write(str(d) + "\0")
      time.sleep(0.05)

if __name__ == "__main__":
  test()

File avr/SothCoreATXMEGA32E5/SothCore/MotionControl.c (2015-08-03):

/*
 * MotionControl.c
 *
 * Author: Hideyuki Takei <hide@soth.io>
 */ 

#include <util/delay.h>
#include "UsartCmdServo.h"
#include "TransitionEasing.h"
#include "xprintf.h"

#define WAIT_TIME 250
#define UP_ANGLE 900
#define DOWN_ANGLE 700
#define CLOSE_ANGLE 0
#define RIGHT_YAW 200
#define LEFT_YAW -250
#define CENTER_YAW -30

// prototypes
void setPositionWithEasing(
    uint16_t currentPosition1, uint16_t goalPosition1,
    uint16_t currentPosition2, uint16_t goalPosition2,
    uint16_t currentPosition3, uint16_t goalPosition3,
    uint16_t currentPosition4, uint16_t goalPosition4,
    uint16_t currentPosition5, uint16_t goalPosition5,
    uint16_t timeMs
);
void bye();
void mendo();

void setStandaloneMotion()
{
    uint16_t goal;
    for(uint8_t a=0; a<255; a++){
        xprintf("%d\n", cubicEaseInOut(a, 300, 400, 255));
    }
    xprintf("\n");
    for(uint8_t a=0; a<255; a++){
        xprintf("%d\n", cubicEaseInOut(a, 700, -400, 255));
    }

    _delay_ms(500);
 
    changeTorqueOnForAllServos();

    _delay_ms(2000);

    setGoalPosition(5, CENTER_YAW);

    _delay_ms(2000);
    setGoalPositionForAllServos(CLOSE_ANGLE, CLOSE_ANGLE, CLOSE_ANGLE, CLOSE_ANGLE, CENTER_YAW);
    _delay_ms(5000);
 
    while(1){
        // move forward
     
        //setGoalPositionAndTimeForAllServos(DOWN_ANGLE, DOWN_ANGLE, DOWN_ANGLE, DOWN_ANGLE, CENTER_YAW, 1000);
        setPositionWithEasing(
            CLOSE_ANGLE, DOWN_ANGLE,
            CLOSE_ANGLE, DOWN_ANGLE,
            CLOSE_ANGLE, DOWN_ANGLE,
            CLOSE_ANGLE, DOWN_ANGLE,
            CENTER_YAW, CENTER_YAW,
            1000
        );

        _delay_ms(2000);

        setPositionWithEasing(
            DOWN_ANGLE, DOWN_ANGLE,
            DOWN_ANGLE, UP_ANGLE,
            DOWN_ANGLE, UP_ANGLE,
            DOWN_ANGLE, DOWN_ANGLE,
            CENTER_YAW, RIGHT_YAW,
            WAIT_TIME
        );
     
        for(int8_t i=0; i<3; i++)
        {
            //setGoalPositionAndTimeForAllServos(UP_ANGLE, UP_ANGLE, UP_ANGLE, UP_ANGLE, RIGHT_YAW, WAIT_TIME);
            setPositionWithEasing(
                DOWN_ANGLE, UP_ANGLE,
                UP_ANGLE, DOWN_ANGLE,
                UP_ANGLE, DOWN_ANGLE,
                DOWN_ANGLE, UP_ANGLE,
                RIGHT_YAW, RIGHT_YAW,
                WAIT_TIME
            );

            //setGoalPositionAndTimeForAllServos(UP_ANGLE, DOWN_ANGLE, DOWN_ANGLE, UP_ANGLE, CENTER_YAW, WAIT_TIME);
            setPositionWithEasing(
                UP_ANGLE, UP_ANGLE,
                DOWN_ANGLE, DOWN_ANGLE,
                DOWN_ANGLE, DOWN_ANGLE,
                UP_ANGLE, UP_ANGLE,
                RIGHT_YAW, LEFT_YAW,
                WAIT_TIME*2
            );

            //setGoalPositionAndTimeForAllServos(UP_ANGLE, UP_ANGLE, UP_ANGLE, UP_ANGLE, LEFT_YAW, WAIT_TIME);
            setPositionWithEasing(
                UP_ANGLE, DOWN_ANGLE,
                DOWN_ANGLE, UP_ANGLE,
                DOWN_ANGLE, UP_ANGLE,
                UP_ANGLE, DOWN_ANGLE,
                LEFT_YAW, LEFT_YAW,
                WAIT_TIME
            );

            //setGoalPositionAndTimeForAllServos(DOWN_ANGLE, UP_ANGLE, UP_ANGLE, DOWN_ANGLE, CENTER_YAW, WAIT_TIME);
            setPositionWithEasing(
                DOWN_ANGLE, DOWN_ANGLE,
                UP_ANGLE, UP_ANGLE,
                UP_ANGLE, UP_ANGLE,
                DOWN_ANGLE, DOWN_ANGLE,
                LEFT_YAW, RIGHT_YAW,
                WAIT_TIME*2
            );
        }

        setPositionWithEasing(
            DOWN_ANGLE, UP_ANGLE,
            UP_ANGLE, UP_ANGLE,
            UP_ANGLE, UP_ANGLE,
            DOWN_ANGLE, UP_ANGLE,
            RIGHT_YAW, CENTER_YAW,
            WAIT_TIME
        );

        setPositionWithEasing(
            UP_ANGLE, CLOSE_ANGLE,
            UP_ANGLE, CLOSE_ANGLE,
            UP_ANGLE, CLOSE_ANGLE,
            UP_ANGLE, CLOSE_ANGLE,
            CENTER_YAW, CENTER_YAW,
            2000
        );

        _delay_ms(5000);

        //_delay_ms(500);

        // move backward

        /*setGoalPositionAndTimeForAllServos(DOWN_ANGLE, DOWN_ANGLE, DOWN_ANGLE, DOWN_ANGLE, CENTER_YAW, 2000);

        _delay_ms(2000);

        setGoalPositionAndTimeForAllServos(CLOSE_ANGLE, CLOSE_ANGLE, CLOSE_ANGLE, CLOSE_ANGLE, CENTER_YAW, 1500);

        _delay_ms(5000);
        setGoalPositionAndTimeForAllServos(DOWN_ANGLE, DOWN_ANGLE, DOWN_ANGLE, DOWN_ANGLE, CENTER_YAW, 1000);
        _delay_ms(1000);

        for(int8_t i=0; i<4; i++)
        {
            setGoalPositionAndTimeForAllServos(DOWN_ANGLE, UP_ANGLE, UP_ANGLE, DOWN_ANGLE, LEFT_YAW, WAIT_TIME);

            _delay_ms(WAIT_TIME);

            setGoalPositionAndTimeForAllServos(UP_ANGLE, UP_ANGLE, UP_ANGLE, UP_ANGLE, LEFT_YAW, WAIT_TIME);

            _delay_ms(WAIT_TIME);

            setGoalPositionAndTimeForAllServos(UP_ANGLE, DOWN_ANGLE, DOWN_ANGLE, UP_ANGLE, LEFT_YAW, WAIT_TIME);

            _delay_ms(WAIT_TIME);

            setGoalPositionAndTimeForAllServos(UP_ANGLE, DOWN_ANGLE, DOWN_ANGLE, UP_ANGLE, CENTER_YAW, WAIT_TIME);

            _delay_ms(WAIT_TIME);

            setGoalPositionAndTimeForAllServos(UP_ANGLE, DOWN_ANGLE, DOWN_ANGLE, UP_ANGLE, RIGHT_YAW, WAIT_TIME);

            _delay_ms(WAIT_TIME);

            setGoalPositionAndTimeForAllServos(UP_ANGLE, UP_ANGLE, UP_ANGLE, UP_ANGLE, RIGHT_YAW, WAIT_TIME);

            _delay_ms(WAIT_TIME);

            setGoalPositionAndTimeForAllServos(DOWN_ANGLE, UP_ANGLE, UP_ANGLE, DOWN_ANGLE, RIGHT_YAW, WAIT_TIME);

            _delay_ms(WAIT_TIME);

            // top
            setGoalPositionAndTimeForAllServos(DOWN_ANGLE, UP_ANGLE, UP_ANGLE, DOWN_ANGLE, CENTER_YAW, WAIT_TIME);

            _delay_ms(WAIT_TIME);
        }*/
    }
}

void setPositionWithEasing(
    uint16_t currentPosition1, uint16_t goalPosition1,
    uint16_t currentPosition2, uint16_t goalPosition2,
    uint16_t currentPosition3, uint16_t goalPosition3,
    uint16_t currentPosition4, uint16_t goalPosition4,
    uint16_t currentPosition5, uint16_t goalPosition5,
    uint16_t timeMs
)
{
    for(uint16_t i=0; i<timeMs/12; i++){
        setGoalPositionForAllServos(
            cubicEaseInOut(i, currentPosition1, (int16_t)goalPosition1-(int16_t)currentPosition1, timeMs/10),
            cubicEaseInOut(i, currentPosition2, (int16_t)goalPosition2-(int16_t)currentPosition2, timeMs/10),
            cubicEaseInOut(i, currentPosition3, (int16_t)goalPosition3-(int16_t)currentPosition3, timeMs/10),
            cubicEaseInOut(i, currentPosition4, (int16_t)goalPosition4-(int16_t)currentPosition4, timeMs/10),
            cubicEaseInOut(i, currentPosition5, (int16_t)goalPosition5-(int16_t)currentPosition5, timeMs/10)
        );
        _delay_ms(10);
    }
}
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

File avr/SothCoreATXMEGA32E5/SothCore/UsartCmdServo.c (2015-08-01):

/*
 * UsartCmdServo.c
 *
 * Author: Hideyuki Takei <hide@soth.io>
 */ 

#include <avr/io.h>
#include <util/delay.h>
#include "UsartCmdServo.h"
#include "SothCore.h"
#include "xprintf.h"

void initUsartCmdServo()
{
	// USARTCO, 115.2kbps, -0.08%
	// BSEL:11, BSCALE:-7
	USARTC0_BAUDCTRLA = 11;
	USARTC0_BAUDCTRLB = USART_BSCALE3_bm | USART_BSCALE0_bm;

	disableUsartCmdServoRx();

	USARTC0_CTRLC = USART_CMODE_ASYNCHRONOUS_gc | USART_CHSIZE_8BIT_gc | USART_PMODE_DISABLED_gc;
}

void enableUsartCmdServoRx()
{
    USARTC0_CTRLB = USART_ONEWIRE_bm | USART_RXEN_bm | USART_CLK2X_bm;
    _cbi(PORTC_DIR, USART_SERVO_PIN);
}

void disableUsartCmdServoRx()
{
    USARTC0_CTRLB = USART_ONEWIRE_bm | USART_TXEN_bm | USART_CLK2X_bm;
    _sbi(PORTC_DIR, USART_SERVO_PIN);
}

uint8_t recieveResponseCmdServo(uint8_t* data)
{
    uint8_t i;
    uint8_t totalLength;
    uint8_t xor = 0;
    
    // Wait until TX buffer empty
    loop_until_bit_is_set(USARTC0.STATUS, USART_DREIF_bp);

    // Wait 50us
    _delay_us(50);
    
    // Enable Rx
    enableUsartCmdServoRx();

    // Wait until recv return packet
    while(1){
        data[0] = getDataCmdServo();
        if(data[0]==CMD_SERVO_RETURN_PACKET_HEADER_L){
            break;
        }
    }

    data[1] = getDataCmdServo();
    data[2] = getDataCmdServo();   // ID
    data[3] = getDataCmdServo();   // Flag
    data[4] = getDataCmdServo();   // Address
    data[5] = getDataCmdServo();   // Length
    data[6] = getDataCmdServo();   // Count

    for(i=0; i<data[5]; i++){
        data[7+i] = getDataCmdServo();
    }

    data[7+data[5]] = getDataCmdServo();

    totalLength = 7+data[5]+1;

    //for(i=0; i<totalLength; i++){
    //    xprintf("data[%d]: 0x%X\r\n", i, data[i]);
    //}

    xor = data[2];
    for(i=3; i<totalLength-1; i++){
        xor ^= data[i];
    }

    // Disable Rx
    disableUsartCmdServoRx();

    if(xor==data[totalLength-1]){
        return CMD_SERVO_RECV_STATUS_OK;
    } else {
        return CMD_SERVO_RECV_STATUS_NG;
    }
}

uint8_t getDataCmdServo()
{
    loop_until_bit_is_set(USARTC0.STATUS, USART_RXCIF_bp);
    return USARTC0.DATA;
}

void sendDataToCmdServo(const char c)
{
	loop_until_bit_is_set(USARTC0.STATUS, USART_DREIF_bp);
	USARTC0.DATA = c;

    //xprintf("%X\n", (uint8_t)c);
}

void sendPacket(uint8_t id, uint8_t flag, uint8_t address, uint8_t length, uint8_t count, uint8_t* data)
{
	uint8_t i, j;
	uint8_t xor;
	
	// Header
	sendDataToCmdServo(CMD_SERVO_SHORT_PACKET_HEADER_L);
	sendDataToCmdServo(CMD_SERVO_SHORT_PACKET_HEADER_H);
	
	// ID
	sendDataToCmdServo(id);
	xor = id;
	
	// Flag
	sendDataToCmdServo(flag);
	xor ^= flag;
	
	// Address
	sendDataToCmdServo(address);
	xor ^= address;
	
	// Length
	sendDataToCmdServo(length);
	xor ^= length;
	
	// Count
	sendDataToCmdServo(count);
	xor ^= count;
	
	// Data
	for(i=0; i<count; i++){
		for(j=0; j<length; j++){
			sendDataToCmdServo(data[i*length + j]);
			xor ^= data[i*length + j];
		}
	}
	
	// Sum
	sendDataToCmdServo(xor);
}

void changeTorqueMode(uint8_t id, uint8_t mode)
{
	uint8_t data[] = {mode};	
	sendPacket(id, CMD_SERVO_SHORT_FLAG_NONE, CMD_SERVO_ADDRESS_TORQUE_ENABLE, 1, 1, data);
}

void setGoalPosition(uint8_t id, int16_t position)
{
    uint8_t data[] = {(uint8_t)(position), (uint8_t)(position>>8)};
    sendPacket(id, CMD_SERVO_SHORT_FLAG_NONE, CMD_SERVO_ADDRESS_GOAL_POSITION_L, 2, 1, data);
}

void writeFlashROM(uint8_t id)
{
    sendPacket(id, CMD_SERVO_SHORT_FLAG_WRITE_ROM, 0xFF, 0, 0, CMD_SERVO_NO_DATA);
}

void rebootCmdServo(uint8_t id)
{
    sendPacket(id, CMD_SERVO_SHORT_FLAG_REBOOT, 0xFF, 0, 0, CMD_SERVO_NO_DATA);
}

void changeIdCmdServo(uint8_t fromId, uint8_t toId)
{
    uint8_t data[] = {toId};
    sendPacket(fromId, CMD_SERVO_SHORT_FLAG_NONE, CMD_SERVO_ADDRESS_SERVO_ID, 1, 1, data);
    
    _delay_ms(10);
    writeFlashROM(toId);
    _delay_ms(10);
    rebootCmdServo(toId);
    _delay_ms(100);
}

void reverseDirection(uint8_t id, uint8_t isReverse)
{
    uint8_t data[1];

    if(isReverse>0){
        // reverse
        data[0] = 0x01;
    } else {
        // not reverse (default)
        data[0] = 0x00;
    }
    sendPacket(id, CMD_SERVO_SHORT_FLAG_NONE, CMD_SERVO_ADDRESS_REVERSE, 1, 1, data);

    _delay_ms(1);
    writeFlashROM(id);
    _delay_ms(1);
    rebootCmdServo(id);
    _delay_ms(10);
}

void setAngleLimit(uint8_t id, int16_t cwAngleLimit, int16_t ccwAngleLimit)
{
    uint8_t dataCW[] = {(uint8_t)(cwAngleLimit), (uint8_t)(cwAngleLimit>>8)};
    sendPacket(id, CMD_SERVO_SHORT_FLAG_NONE, CMD_SERVO_ADDRESS_CW_ANGLE_LIMIT_L, 2, 1, dataCW);

    _delay_ms(1);

    uint8_t dataCCW[] = {(uint8_t)(ccwAngleLimit), (uint8_t)(ccwAngleLimit>>8)};
    sendPacket(id, CMD_SERVO_SHORT_FLAG_NONE, CMD_SERVO_ADDRESS_CCW_ANGLE_LIMIT_L, 2, 1, dataCCW);

    _delay_ms(1);
    writeFlashROM(id);
    _delay_ms(1);
    rebootCmdServo(id);
    _delay_ms(10);
}

void setGoalPositionForAllServos(int16_t position1, int16_t position2, int16_t position3, int16_t position4, int16_t position5)
{
    uint8_t data[] = {
        (uint8_t)1, (uint8_t)(position1), (uint8_t)(position1>>8), 
        (uint8_t)2, (uint8_t)(position2), (uint8_t)(position2>>8),
        (uint8_t)3, (uint8_t)(position3), (uint8_t)(position3>>8),
        (uint8_t)4, (uint8_t)(position4), (uint8_t)(position4>>8),
        (uint8_t)5, (uint8_t)(position5), (uint8_t)(position5>>8)
    };
    // Use long packet
    sendPacket(0, CMD_SERVO_SHORT_FLAG_NONE, CMD_SERVO_ADDRESS_GOAL_POSITION_L, 3, CMD_SERVO_COUNT, data);
}

void setGoalPositionAndTimeForAllServos(int16_t position1, int16_t position2, int16_t position3, int16_t position4, int16_t position5, uint16_t time)
{
    uint16_t time10ms = time/10;
    uint8_t data[] = {
        (uint8_t)1, (uint8_t)(position1), (uint8_t)(position1>>8), (uint8_t)(time10ms), (uint8_t)(time10ms>>8),
        (uint8_t)2, (uint8_t)(position2), (uint8_t)(position2>>8), (uint8_t)(time10ms), (uint8_t)(time10ms>>8),
        (uint8_t)3, (uint8_t)(position3), (uint8_t)(position3>>8), (uint8_t)(time10ms), (uint8_t)(time10ms>>8),
        (uint8_t)4, (uint8_t)(position4), (uint8_t)(position4>>8), (uint8_t)(time10ms), (uint8_t)(time10ms>>8),
        (uint8_t)5, (uint8_t)(position5), (uint8_t)(position5>>8), (uint8_t)(time10ms), (uint8_t)(time10ms>>8)
    };
    // Use long packet
    sendPacket(0, CMD_SERVO_SHORT_FLAG_NONE, CMD_SERVO_ADDRESS_GOAL_POSITION_L, 5, CMD_SERVO_COUNT, data);
}

void changeTorqueModeForAllServos(uint8_t mode1, uint8_t mode2, uint8_t mode3, uint8_t mode4, uint8_t mode5)
{
    uint8_t data[] = {
        (uint8_t)1, (uint8_t)(mode1),
        (uint8_t)2, (uint8_t)(mode2),
        (uint8_t)3, (uint8_t)(mode3),
        (uint8_t)4, (uint8_t)(mode4),
        (uint8_t)5, (uint8_t)(mode5)
    };
    // Use long packet
    sendPacket(0, CMD_SERVO_SHORT_FLAG_NONE, CMD_SERVO_ADDRESS_TORQUE_ENABLE, 2, CMD_SERVO_COUNT, data);
}
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

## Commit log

2015-04-05 add usart initilization func.
    [Baudrate_Calculations.xls]
2015-04-11 add suart library and atxmega library for pcb.
2015-04-12 add VPORT settings. Software UART works fine.
2015-05-22 add pcb data.
    [soth-core.brd, soth-core.sch]
2015-05-22 add current circuit schematic
    [soth-core.sch]
2015-05-23 add schematic image.
    [soth-core.brd]
2015-05-29 change pullup voltage of 3 state buffers from 3V3 to 5V0
    [soth-core.sch]
2015-05-29 Add Command Servo functions.
    [Baudrate_Calculations.xls]
2015-05-30 Add command servo recv functions.
2015-05-30 woops... GPS baudrate and update rate was reseted.
    [SothCore.c, UsartCmdServo.c, UsartCmdServo.h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]
2015-05-30 implemented changing servo id function.
2015-05-30 apply unique servo id.
2015-06-06 add i2c code
    [soth-core.brd, soth-core.sch]
2015-06-06 add queue for I2C
2015-06-07 I2C multi bytes sending doesn't work
    [I2C.c, SothCore.c]
2015-06-15 Created v0.1
    [soth-core.GBL, soth-core.GBO, soth-core.GBP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]
2015-06-16 add beta-Gnd and ext board.
    [panelize-core1.GBL, panelize-core1.GBO, panelize-core1.GBP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]
2015-06-16 add sent pcb files to Elecrow
2015-06-28 Bugfix pcb design. Replace LDO parts.
    [soth-core.brd, soth-core.sch]
2015-06-29 remove current avr project.
2015-07-04 Change microcontroller from atxmega32d4 to atxmega32e5
    [soth-core.brd, soth-core.sch]
2015-07-04 succcessfully tx/rx data from command servos
2015-07-04 Successfully gps data rcv.
    [soth-ext.brd, soth-ext.sch]
2015-07-05 Bugfix BME280 sensors handling
    [BME280.c, SothCore.c]
2015-07-05 add files of 9Axis sensor MPU-9150

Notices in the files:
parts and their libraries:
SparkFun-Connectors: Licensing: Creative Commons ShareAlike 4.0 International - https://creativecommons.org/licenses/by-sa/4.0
